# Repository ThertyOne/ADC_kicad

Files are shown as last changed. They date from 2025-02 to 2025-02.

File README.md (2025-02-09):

# mini-project ADC

## Opis projektu
Projekt przedstawia układ do precyzyjnej konwersji analogowo-cyfrowej oparty na przetworniku ADC ADS8881, wspomaganym przez wzmacniacze operacyjne oraz stabilizatory napięcia. Układ został zoptymalizowany względem poprzedniej wersji, uwzględniając poprawki dotyczące źródła napięcia referencyjnego, filtracji sygnału wejściowego oraz zasilania.

## Zmiany względem poprzedniej wersji
1. **Implementacja układu z rysunku 70 z dokumentacji ADS8881** – poprawiona konfiguracja układu przetwornika ADC.
2. **Napięcie referencyjne** pochodzi teraz ze stabilizatora LDO, które również zasila wzmacniacze operacyjne w układzie. Napięcie wejściowe wynosi 12V.
3. **Filtr wejściowy** został poprawiony – zastosowano górnoprzepustowy filtr o częstotliwości odcięcia **48 Hz**.
4. **Dodano stabilizator napięcia 3V**, który zasila przetwornik ADS8881, zgodnie z jego specyfikacją (dopuszczalne napięcie zasilania od 2.7V do 3.6V).

## Kluczowe elementy układu
- **Mikrokontroler**: Raspberry Pi Pico – sterowanie przetwornikiem ADC.
- **Przetwornik ADC**: ADS8881 – 18-bitowy, szybki i precyzyjny konwerter analogowo-cyfrowy.
- **Stabilizatory napięcia**:
  - **TPS7A49** – stabilizator napięcia referencyjnego.
  - **LM4040** – dodatkowe źródło referencyjne 3V dla ADS8881.
- **Wzmacniacze operacyjne**:
  - **OPA320** – wzmacniacz buforujący sygnał wejściowy.
  - **THS4521** – różnicowy wzmacniacz sygnału dla przetwornika ADC.

## Power Supply (LDO)
Układ zawiera kilka wzmacniaczy operacyjnych, które wymagają stabilnego zasilania. Wybrano zasilanie 5V, ponieważ wszystkie użyte wzmacniacze operacyjne mogą pracować przy tym napięciu. Stabilizator niskoszumowy (LDO) **TPS7A49** został wybrany ze względu na swoje niskie szumy (15,4 µV RMS) oraz prostą konfigurację napięcia wyjściowego przy użyciu jedynie dwóch rezystorów. Dodatkowo zastosowano diodę TVS do ochrony układu przed przepięciami oraz wskaźnik napięcia wyjściowego 5V.

## LM4040 Voltage Reference
Aby zasilić zarówno sekcję analogową, jak i cyfrową przetwornika **ADS8881** (który działa w zakresie 2,7V - 3,6V), użyto stabilizatora **LM4040**, który konwertuje 5V z LDO na 3V dla ADC. Dzięki temu poziomy logiczne na wyjściu ADC będą miały maksymalne napięcie 3V, co nie stanowi problemu dla **Raspberry Pi Pico**, gdyż powinien on niezawodnie rozpoznawać 2,7V jako wysoki poziom logiczny.

## Input Signal Processing
Sygnał wejściowy z fotodiody przechodzi przez filtr górnoprzepustowy **50 Hz**, a następnie przez wzmacniacz, który wzmacnia sygnał i izoluje go od obciążenia.

## Analog-to-Digital Conversion (ADC)
Zgodnie z zaleceniami z poprzedniego maila wdrożono konfigurację **ADS8881** zgodnie z **rysunkiem 70** z dokumentacji. Konfiguracja ta jest zasilana **5V z LDO**, które jednocześnie pełni rolę napięcia referencyjnego dla ADC. Jak wspomniano wcześniej, sam ADC jest zasilany napięciem **3V ze stabilizatora LM4040**, a obie sekcje – analogowa i cyfrowa – są wyposażone w **kondensatory odsprzęgające 1µF**. Linie komunikacyjne są podłączone do **Raspberry Pi Pico**, które odpowiada wyłącznie za wyzwalanie pomiaru i odczyt danych z ADC.

## Schemat
Projekt został opracowany w **KiCad** i zapisany w pliku `adc.kicad_sch`. Schemat zawiera podział na bloki funkcjonalne:
- Stabilizacja napięcia (LDO, stabilizator 3V)
- Filtracja sygnału wejściowego (filtr górnoprzepustowy)
- Konwersja analogowo-cyfrowa (ADS8881 + wzmacniacze operacyjne)
- Sterowanie i komunikacja z mikrokontrolerem

## Wymagane napięcia
- **Vin**: 12V
- **Vref**: 5V (ze stabilizatora LDO)
- **Zasilanie ADC**: 3V

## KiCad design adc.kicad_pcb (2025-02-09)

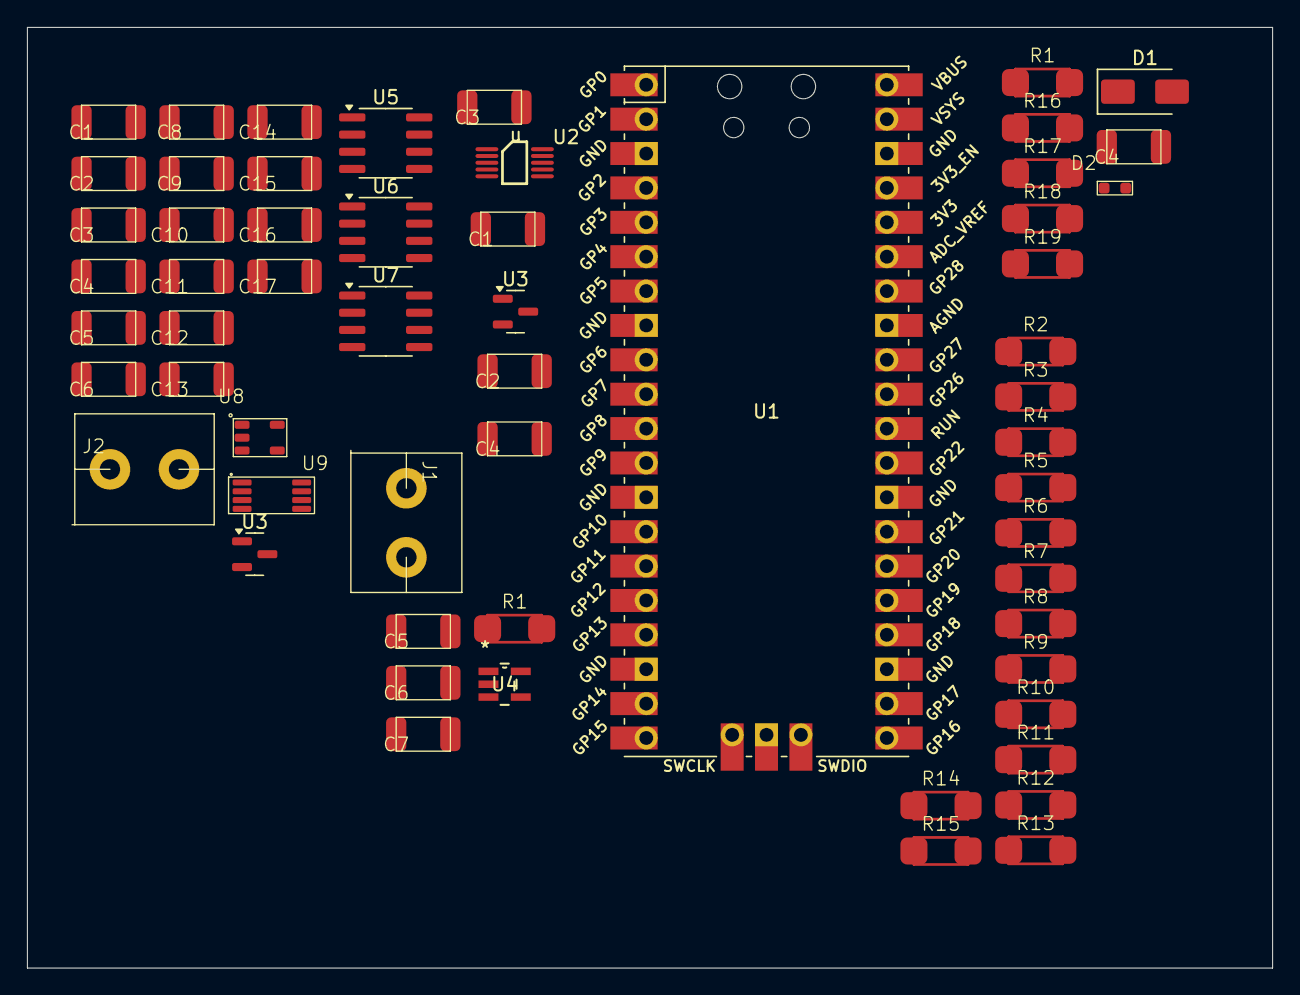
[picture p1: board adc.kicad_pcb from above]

Board: 2 copper layers, 92.0 x 69.5 mm, 58 parts (0 on the bottom side), 32 nets, no tracks yet.

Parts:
C1, C2, C3, C3#2, C4#2, C6, C12, C13: 1u; cap_1206
C1#2, C4, C5#2, C6#2, C11, C14, C17: 10u; cap_1206
C2#2, C5, C9, C10: 100n; cap_1206
C4#3, C7: 33u; cap_1206
C8, C15, C16: 10n; cap_1206
D1: SMAJ12A; D_SMA
D2: LED; LED_SMD
J1, J2: Screw_Terminal_01x02; screw_conector
R1, R1#2, R14, R19: 100; res_1206
R2, R4, R8, R9, R10, R11, R13: 1k; res_1206
R3: 0.2; res_1206
R5: 20k; res_1206
R6, R7: 10; res_1206
R12: 4.7k; res_1206
R15, R18: 10k; res_1206
R16: 400; res_1206
R17: 470; res_1206
U1: Pico; RPi_Pico_SMD_TH
U2: ADS8881CDGS; ADS8881
U3, U3#2: LM4040DBZ-3; SOT-23
U4: OPA320AIDBVR; DBV5
U5: THS4521ID; SOIC-8_3.9x4.9mm_P1.27mm
U6: OPA333xxD; SOIC-8_3.9x4.9mm_P1.27mm
U7: REF5045AD; SOIC-8_3.9x4.9mm_P1.27mm
U8: THS4281
U9: TPS7A49

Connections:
3.3V: C1#2.1, C2#2.1, C3#2.1, C4#2.1, C5.1, C6#2.1, U1.36 (3V3), U3.1 (K)
+3: C4.1, C9.1, C10.1, C11.1, C12.1, C13.1, R16.2, U2.2 (AVDD), U2.10 (DVDD), U3#2.1 (K)
+5: C16.1, C17.1, D2.2 (A), R12.1, R14.1, R16.1, U4.5 (V+), U5.3 (V_{S+}), U5.7 (~PD), U6.7 (V+), U7.2 (Vin), U8.5 (V+), U9.1 (OUT)
CONVS: U1.2 (GPIO1), U2.6 (CONVST)
DIN: U1.5 (GPIO3), U2.9 (DIN)
DIODE_IN: C7.2, R1#2.1
DIODE_SIGNAL: R11.2, R18.1, U4.1
DOUT: U1.1 (GPIO0), U2.7 (DOUT)
GND: C1#2.2, C2.2, C2#2.2, C3.2, C3#2.2, C4.2, C4#2.2, C5.2, C5#2.2, C6.2, C6#2.2, C9.2, C10.2, C11.2, C12.2, C13.2, C14.2, C15.2, C17.2, D1.2 (A2), J1.2, J2.2, R1.2, R1#2.2, R9.1, R13.2, R17.2, R19.2, U1.28 (GND), U1.42 (GND), U2.5 (GND), U3.2 (A), U3#2.2 (A), U4.2 (V-), U5.6 (V_{S-}), U6.4 (V-), U7.4 (GND), U8.2 (V-), U9.4 (GND)
unnamed: C1.1, R4.1, U6.6
unnamed: C5#2.1, R3.2
unnamed: C14.1, D1.1 (A1), J2.1, U9.5 (EN), U9.8 (IN)
unnamed: D2.1 (K), R17.1
unnamed: C4#3.1, J1.1
unnamed: R7.2, R8.1, U5.4
unnamed: R6.2, R10.1, U5.5
unnamed: R14.2, R15.1
unnamed: C8.2, R7.1, U2.4 (AINM)
unnamed: C8.1, R6.1, U2.3 (AINP)
unnamed: C4#3.2, R1.1, U4.3 (+)
unnamed: R18.2, R19.1, U4.4 (-)
unnamed: R10.2, R11.1, U5.8 (+)
unnamed: R8.2, R9.2, U5.1 (-)
unnamed: C6.1, R2.2, U6.3 (+)
unnamed: C1.2, R5.1, U6.2 (-)
unnamed: C3.1, U7.5 (Trim/NR)
unnamed: R2.1, U7.6 (Vout)
unnamed: C2.1, R4.2, U8.3 (+)
unnamed: C16.2, R12.2, R13.1, R15.2, U9.2 (FB)
unnamed: C15.1, U9.6 (NE/SS)
SCLK: U1.4 (GPIO2), U2.8 (SCLK)
V_REF: R3.1, R5.2, U2.1 (REF), U5.2 (V_{OCM}), U8.1, U8.4 (-)
